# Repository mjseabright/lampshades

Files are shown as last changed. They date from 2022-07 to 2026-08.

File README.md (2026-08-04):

# Lampshades
A collection of 3D printable lampshades designed in OpenSCAD. More information on my [website](tartartech.xyz/lampshades) and STLs on [Printables](https://www.printables.com/social/308094-mjseabright/collections/207685).

## Where Are The STLs
They are [here](https://www.printables.com/social/308094-mjseabright/collections/207685). Some of them are quite big files, so they are hosted on Printables rather than GitHub. 

## Editing the Designs
All of the designs are done in [OpenSCAD](https://openscad.org/), so just [download](https://openscad.org/downloads.html) and install OpenSCAD and get to work. Each design's shape lives as a reusable module in `<design>.scad`, e.g. [turbine.scad](turbine/turbine.scad). To actually print one, open one of the sibling files that sets the dimensions and calls that module, e.g. [turbine_small.scad](turbine/turbine_small.scad) or [turbine_large.scad](turbine/turbine_large.scad) — that's where the main dimension parameters are, making them easily customisable. I suggest you change the layer height parameter to something like 2mm (rather than 0.2mm) while playing around with designs as it will be much quicker. Then change it back for the final render.

A couple of helper files at the repo root, [geometry_functions.scad](geometry_functions.scad) and [mounting_functions.scad](mounting_functions.scad), hold shapes shared across multiple designs (polygons, center holes, foot-mounting holes). You generally shouldn't need to touch these unless you want to change how the lampshade is mounted.

The [noise](noise/) design is different as it uses [Python](https://www.python.org/) to generate a SCAD file that then gets rendered via OpenSCAD. Changes can be made via the parmeters at the top of the [noisey_generator.py](noise/noisey_generator.py) file. Running it will generate a new [noisey.scad](noise/noisey.scad) file, which can then be rendered by OpenSCAD.

## Lamp Compatibility
I designed the lampshades to work with standard shade mounting systems. I've been using lamp bases that take an E14 bulb and have a ~28mm diameter male thread for the shade mounting. The [adaptor](adaptor/adaptor.scad) dimensions can be adjusted to fit larger light sockets.

Here is a picture of the socket on the lamp base I have been using:
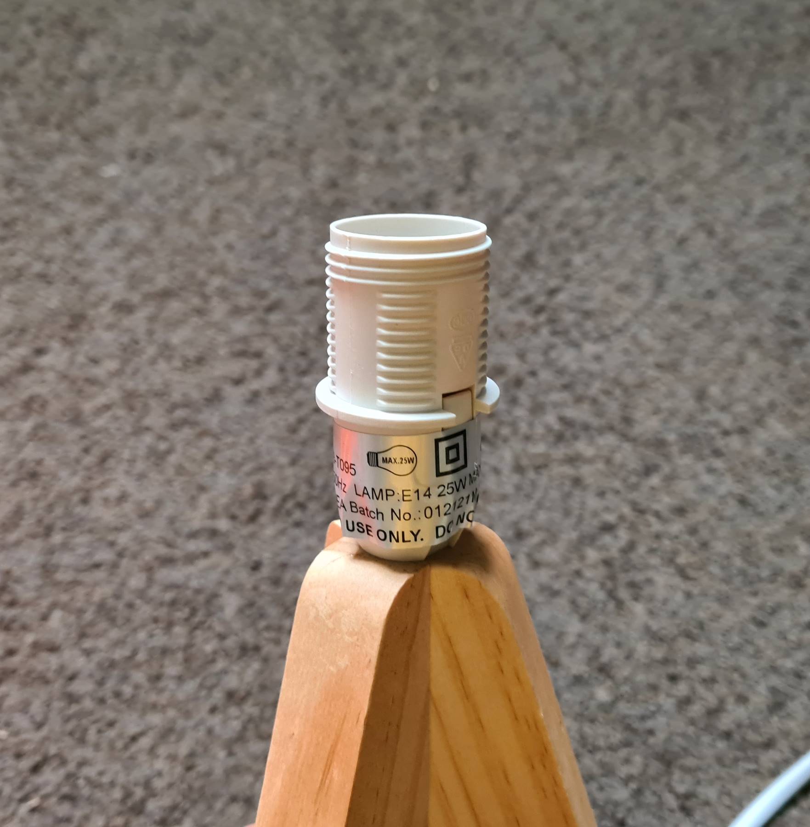
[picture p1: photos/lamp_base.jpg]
Lamp socket image


## Print Settings and Tips
All of these lampshades are designed to be printed in vase mode (single wall spiral printing). I used the following settings and found they worked well:
- Material: PETG (PLA works fine but may warp if you use an incandecent bulb or leave it in direct sunlight)
- Layer height: 0.2mm
- Line width: 0.6mm
- Solid bottom layers: 6
- Some of the designs look good using the ['fuzzy skin'](https://help.prusa3d.com/article/fuzzy-skin_246186) feature of PrusaSlicer or Cura

Print both the lampshade you like and the [adaptor](adaptor/adaptor.scad). I print the adaptor with normal settings (ie. not vase mode). I ususally use PETG and a 0.3mm layer height. It does require supports unfortunatly. Then glue the adaptor into the bottom of the lampshade with CA glue. Here are some pictures to show you what I mean:

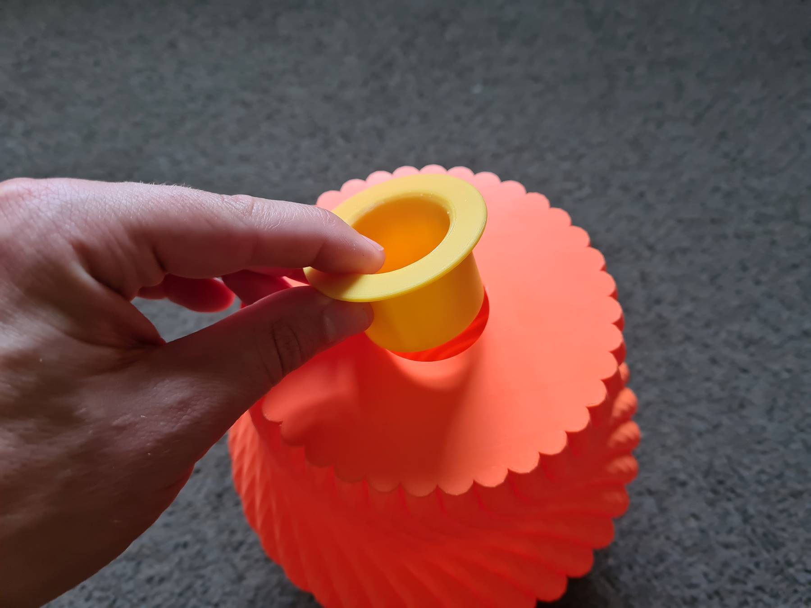
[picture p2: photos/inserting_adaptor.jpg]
Inserting the adaptor

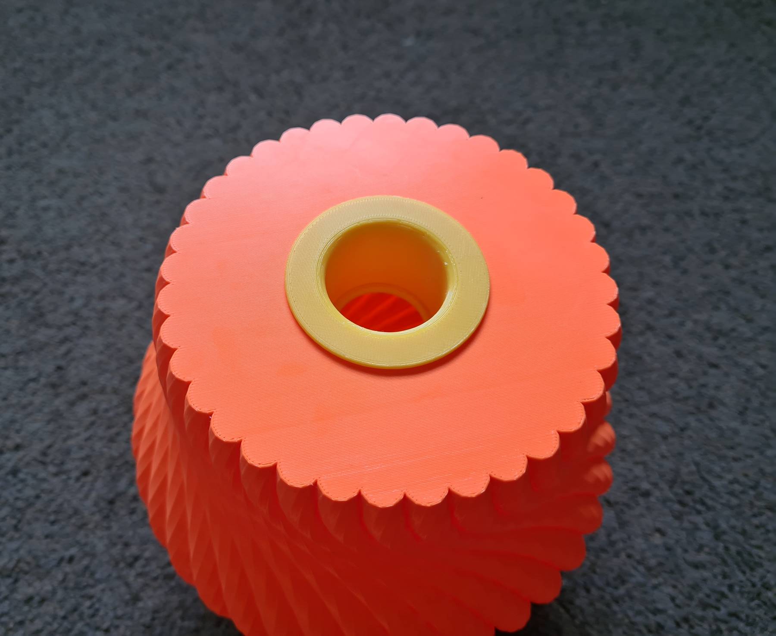
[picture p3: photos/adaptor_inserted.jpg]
Adaptor inserted


## Photos
See the [photos](photos/) folder for more photos of the designs.
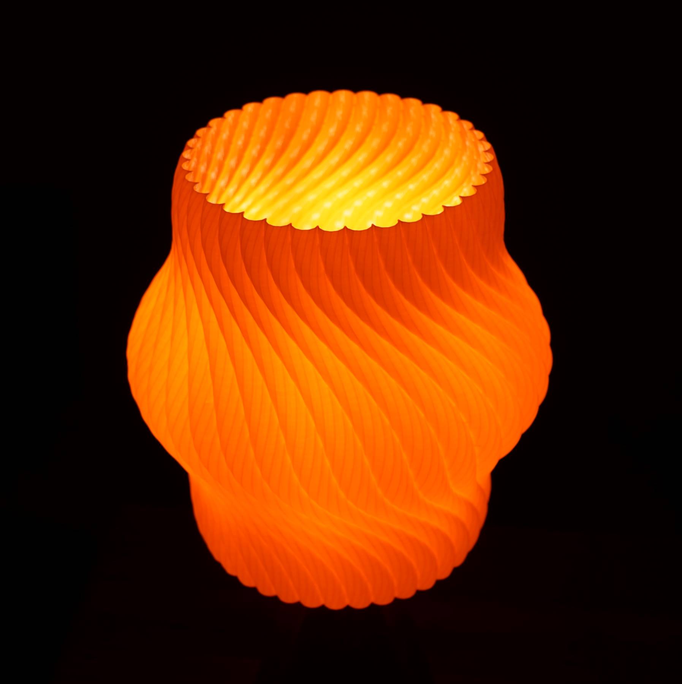
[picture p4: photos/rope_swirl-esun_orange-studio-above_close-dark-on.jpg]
A lamp

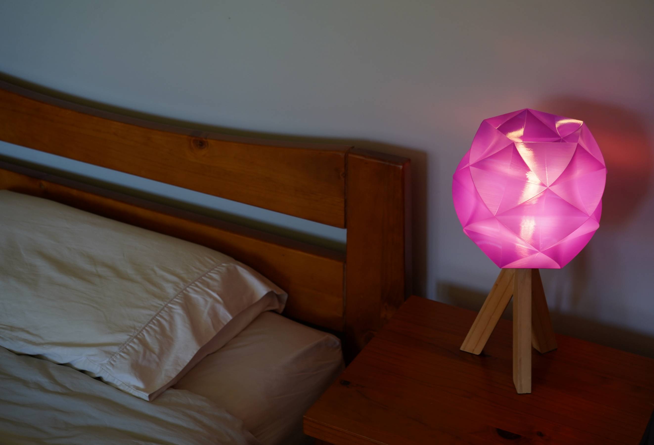
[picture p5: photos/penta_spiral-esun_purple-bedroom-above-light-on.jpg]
Another lamp

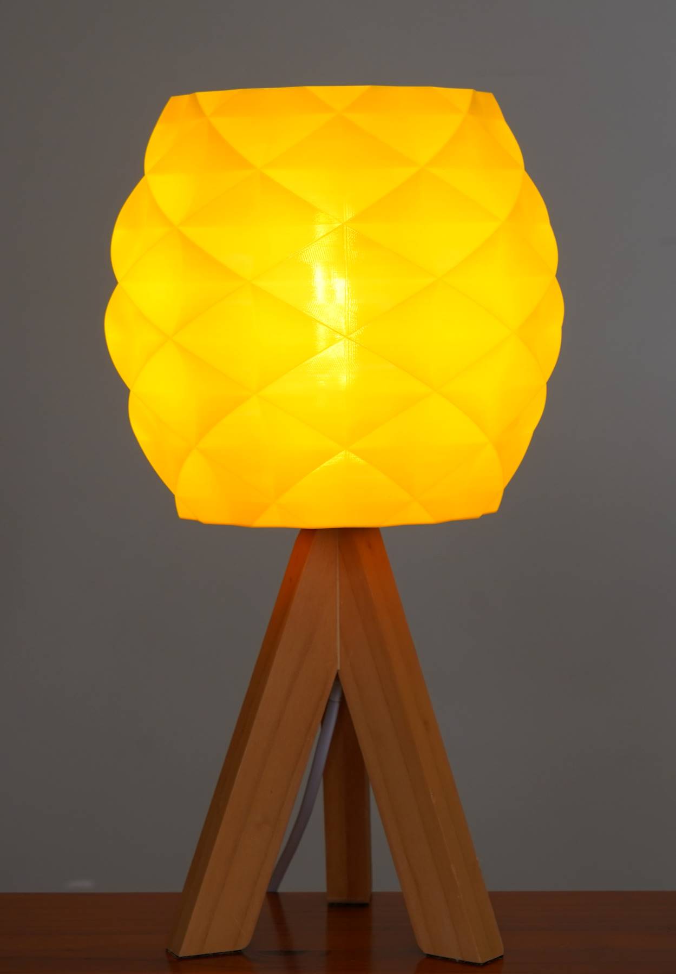
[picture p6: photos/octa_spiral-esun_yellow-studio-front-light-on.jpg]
Wow, another lamp


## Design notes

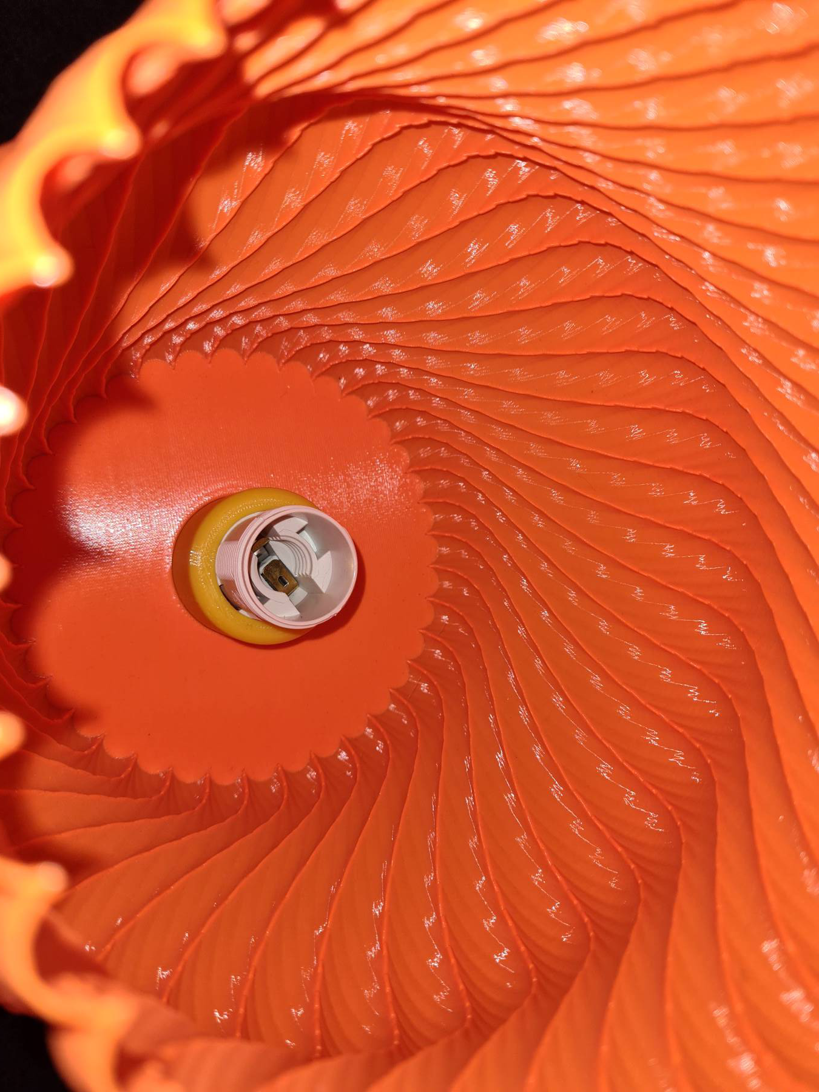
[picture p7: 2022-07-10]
photos/inside.jpg

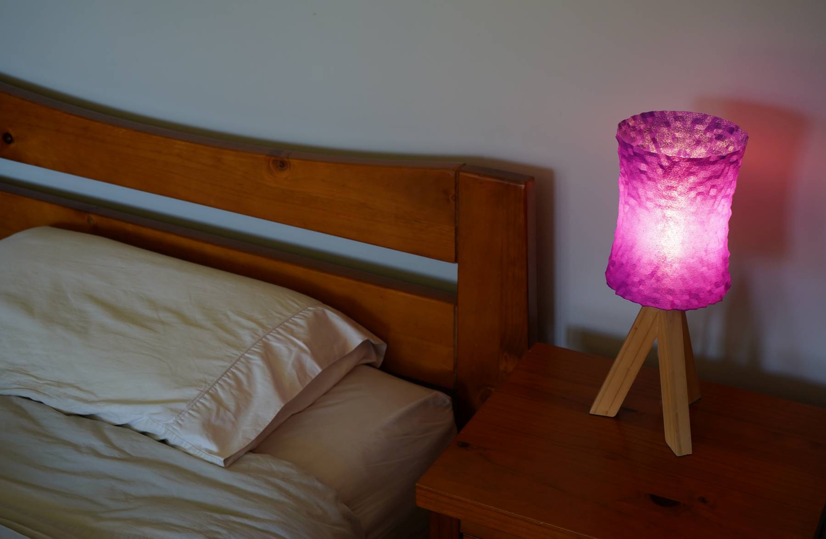
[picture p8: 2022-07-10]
photos/concave_noise_fuzz-esun_purple-bedroom-above-light-on.jpg

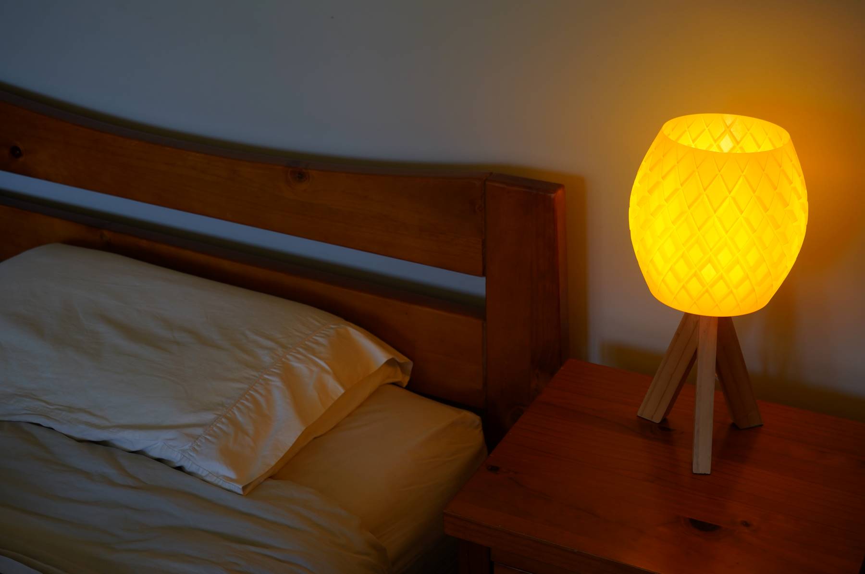
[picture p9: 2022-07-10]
photos/pineapple-esun_yellow-bedroom-above-light-on.jpg

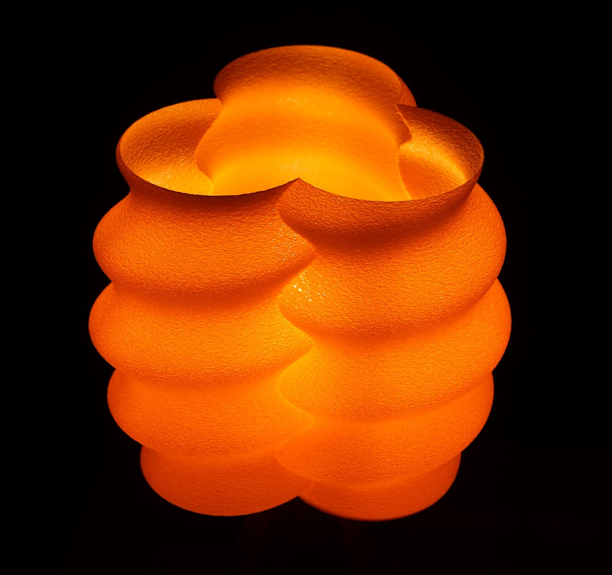
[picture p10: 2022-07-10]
photos/lava_swirl_fuzz-esun_orange-studio-above_close-dark-on.jpg

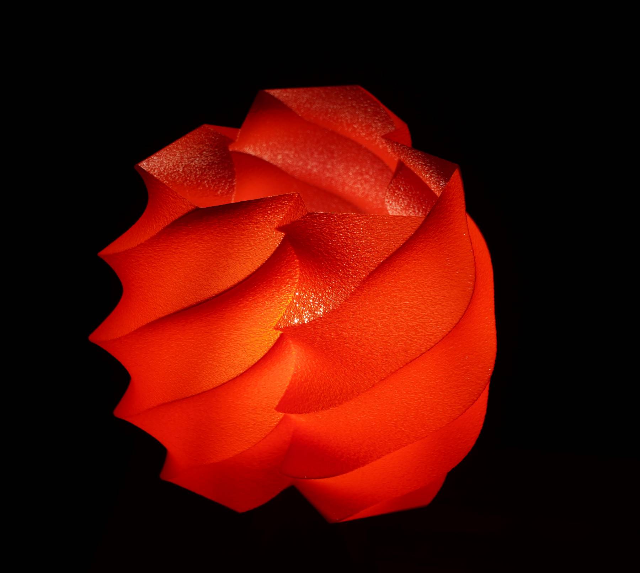
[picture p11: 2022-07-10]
photos/pentagon_turbine_fuzz-esun_red-studio-above_close-dark-on.jpg

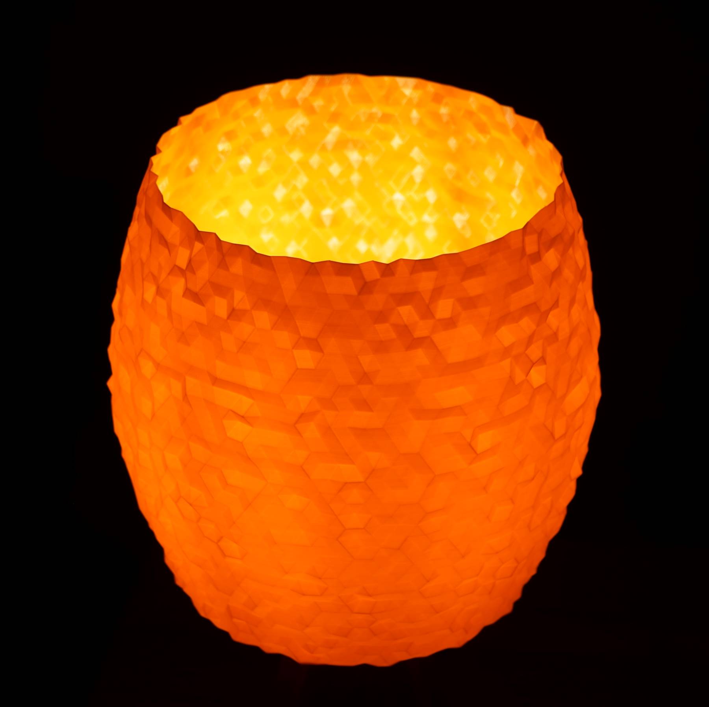
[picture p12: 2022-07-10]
photos/convex_noise-esun_orange-studio-above_close-dark-on.jpg

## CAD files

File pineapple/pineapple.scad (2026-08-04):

use <../geometry_functions.scad>;

module pineapple(height = 180, layer_height = 0.2, main_diameter = 130, num_angle_divs = 40) {
    for (h = [0:layer_height:height]) {
        layer_diameter = main_diameter + 40 * sin((h / height) * 180);
        triangle_ratio = ((h / 10) % 4 >= 2) ? (h / 10) % 2 : 2 - ((h / 10) % 2);

        translate([0,0,h]) linear_extrude (layer_height) intersection() {
            circle(d = layer_diameter + 0 + (12 * sin((h / height) * 180)), $fn=180);
            union() {
                for (theta = [0 : 2 * 360 / num_angle_divs : 360]) {
                    triangle_side_length = triangle_ratio * layer_diameter * cos(((num_angle_divs - 2) * 180) / (2 * num_angle_divs));
                    triangle_radius = regular_polygon_radius_from_side_length(order = 3, side_length = triangle_side_length);
                    triangle_position_offset = sqrt((layer_diameter / 2)^2 - (triangle_side_length / 2)^2);

                    rotate([0,0,theta]) translate([triangle_position_offset + triangle_radius * sin(30), 0, 0]) regular_polygon(order = 3, r = triangle_radius);
                }

                for (theta = [0 : 2 * 360 / num_angle_divs : 360]) {
                    triangle_side_length = (2 - triangle_ratio) * layer_diameter * cos(((num_angle_divs - 2) * 180) / (2 * num_angle_divs));
                    triangle_radius = regular_polygon_radius_from_side_length(order = 3, side_length = triangle_side_length);
                    triangle_position_offset = sqrt((layer_diameter / 2)^2 - (triangle_side_length / 2)^2);

                    rotate([0,0,theta + 360 / num_angle_divs]) translate([triangle_position_offset + triangle_radius * sin(30), 0, 0]) regular_polygon(order = 3, r = triangle_radius);
                }

                circle(d = layer_diameter + 0.5, $fn=180);
            }
        }
    }
}

// Standalone preview with default parameters
pineapple();

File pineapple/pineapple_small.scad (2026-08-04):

use <pineapple.scad>;
use <../mounting_functions.scad>;

height = 180;
layer_height = 0.2;
main_diameter = 130;
num_angle_divs = 40;
center_hole_diameter = 40;

difference() {
    pineapple(height = height, layer_height = layer_height, main_diameter = main_diameter, num_angle_divs = num_angle_divs);
    center_hole(height = height, diameter = center_hole_diameter);
}

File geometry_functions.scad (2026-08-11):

module regular_polygon(order = 5, r=1){
     angles=[ for (i = [0:order-1]) i*(360/order) ];
     coords=[ for (th=angles) [r*cos(th), r*sin(th)] ];
     polygon(coords);
 }

function regular_polygon_side_length(order = 3, r = 1) = 2 * r * sin(360 / (2 * order));
function regular_polygon_radius_from_side_length(order = 3, side_length = 10) = side_length / (2 * sin(360 / (2 * order)));

// Solid cylinder with its outer top and/or bottom edge chamfered (45 degrees
// by default, since the radial and vertical cut both equal `chamfer`). Set
// chamfer_top/chamfer_bottom to false for an end that isn't a real exposed
// face (e.g. it butts against another part) -- chamfering a hidden seam
// creates a visible necked-in groove where the two parts meet.
module chamfered_cylinder(h, d, chamfer, fn = 64, chamfer_top = true, chamfer_bottom = true) {
    r = d / 2;
    bottom_pts = chamfer_bottom ? [[0, 0], [r - chamfer, 0], [r, chamfer]] : [[0, 0], [r, 0]];
    top_pts = chamfer_top ? [[r, h - chamfer], [r - chamfer, h], [0, h]] : [[r, h], [0, h]];
    rotate_extrude($fn = fn) polygon(points = concat(bottom_pts, top_pts));
}

// Cutter for a hole with a countersink chamfer at the z=0 and/or z=h faces.
// Subtract this instead of a plain cylinder to chamfer a hole's edges.
// Self-extends slightly past both faces, so no manual translate/epsilon is
// needed at the call site. Set chamfer_top/chamfer_bottom to false for a
// blind end that isn't a real exposed face -- otherwise the countersink
// flares open inside the solid instead of breaking a real edge.
module chamfered_hole(h, d, chamfer, fn = 32, chamfer_top = true, chamfer_bottom = true) {
    eps = 0.5;
    z0 = chamfer_bottom ? -eps : 0;
    z1 = chamfer_top ? h + eps : h;
    union() {
        translate([0, 0, z0]) cylinder(h = z1 - z0, d = d, $fn = fn);
        if (chamfer_bottom) {
            cylinder(h = chamfer, d1 = d + 2 * chamfer, d2 = d, $fn = fn);
        }
        if (chamfer_top) {
            translate([0, 0, h - chamfer]) cylinder(h = chamfer, d1 = d, d2 = d + 2 * chamfer, $fn = fn);
        }
    }
}

// Linear-extrudes a CONVEX 2D child shape into a solid with both the top and
// bottom outer edges chamfered, by hull-lofting a shrunk copy of the profile
// up to full size over the chamfer height at each end. Only valid for convex
// profiles -- hull() will fill in any concavity (e.g. a hole), so cut those
// afterwards with a separate difference(), not inside the extruded child.
module chamfered_extrude(h, chamfer) {
    union() {
        hull() {
            linear_extrude(0.01) offset(delta = -chamfer) children();
            translate([0, 0, chamfer]) linear_extrude(0.01) children();
        }
        translate([0, 0, chamfer]) linear_extrude(h - 2 * chamfer) children();
        hull() {
            translate([0, 0, h - chamfer]) linear_extrude(0.01) children();
            translate([0, 0, h - 0.01]) linear_extrude(0.01) offset(delta = -chamfer) children();
        }
    }
}

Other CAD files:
mounting_functions.scad
adaptor/adaptor.scad
bases/low_pro_with_adaptor.scad
double_rotated_octagon/rotated_octogon.scad
double_rotated_octagon/rotated_octogon_small.scad
double_rotated_pentagon/double_rotated_pentagon.scad
double_rotated_pentagon/double_rotated_pentagon_small.scad
feet/low_profile_foot.scad
feet/low_profile_foot_insert.scad
feet/low_profile_foot_plastic_thread.scad
fish_tail/fish_tail.scad
fish_tail/fish_tail_small.scad
golfball/golfball.scad
golfball/golfball_small.scad
noise/noisey.scad
rope_swirl/rope_swirl.scad
rope_swirl/rope_swirl_large.scad
rope_swirl/rope_swirl_large_base.scad
rope_swirl/rope_swirl_small.scad
rotated_star/rotated_star.scad
rotated_star/rotated_star_small.scad
screw_compressor/screw_compressor.scad
screw_compressor/screw_compressor_small.scad
triple_spring/triple_spring.scad
triple_spring/triple_spring_small.scad
turbine/turbine.scad
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

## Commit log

2022-07-10 Added all the things
    [adaptor.scad, double_rotated_pentagon.scad, golfball.scad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]
2022-07-13 Added fish tail
    [fish_tail.scad]
2026-08-01 Add turbine_large.scad, a scaled-up variant of turbine.scad for larger printers
    Scaled to fit a 256mm build volume (240mm height, ~240mm XY), with twist
    rates expressed as full rotations over height, named/commented variables
    throughout, and separate center/foot mounting holes.
    [turbine.scad, turbine_large.scad]
2026-08-04 Refactor designs into reusable geometry modules with separate config files
    Each design's core shape now lives in a parameterized module in <design>.scad,
    so the same geometry can be reused across different size/mounting configs
    instead of being duplicated per variant. <design>_small.scad (and
    turbine_large.scad) hold the parameters for a specific variant and add
    mounting features on top.
    Shared helpers pulled out to their own files: regular_polygon and friends
    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
    [double_rotated_pentagon.scad, double_rotated_pentagon_small.scad, fish_tail.scad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]
2026-08-04 Update README to reflect module/config-file refactor
    Editing the Designs now points at the <design>_small/_large config files
    for dimensions rather than the module file itself, and mentions the shared
    geometry_functions.scad/mounting_functions.scad helpers.
2026-08-04 Add bullet-shaped foot design with insert and plastic-thread variants
    Outer profile is a bezier nose revolved with rotate_extrude, tangent to
    the cylindrical body so there's no sharp shoulder, tapering to a rounded
    point. The two variants share the same foot.scad module and differ only
    in center hole diameter (threaded insert vs. self-tapping screw).
    [foot.scad, low_profile_foot_insert.scad, low_profile_foot_plastic_thread.scad]
2026-08-04 Rename feet/foot.scad to low_profile_foot.scad
    Clarifies that this module is specifically for the low-profile foot
    design, not a generic foot shape. Update the variant files' use
    statements accordingly.
    Also pick up a small README wording tweak.
    [low_profile_foot.scad, low_profile_foot_insert.scad, low_profile_foot_plastic_thread.scad]
2026-08-05 Add reusable base module and turbine_large base file
    low_pro_with_adaptor is a placeholder base module (spokes, foot holes,
    adaptor mount boss) in bases/, plus turbine_large_base.scad which wires
    it up with turbine_large.scad's shared parameters so the shade and base
    render as separate STLs.
    [low_pro_with_adaptor.scad, turbine_large.scad, turbine_large_base.scad]
2026-08-11 Taper spokes and flesh out low_pro_with_adaptor base geometry
    Spokes now taper from a wider spoke_width_center at the hub down to
    spoke_width at the foot-hole tip instead of being constant-width
    rectangles. Also fills in the previously placeholder spoke/rim geometry
    and tunes mount/spoke dimensions, wired through in turbine_large_base.
    [low_pro_with_adaptor.scad, turbine_large_base.scad]
2026-08-11 Add chamfered top/bottom edges to low_pro_with_adaptor base
    Adds chamfered_cylinder, chamfered_hole, and chamfered_extrude helpers
    to geometry_functions.scad and uses them throughout the base's boss,
    disc, spokes, and holes so every real exposed XY-plane face gets a
    0.5mm edge break, without chamfering hidden seams or blind ends.
    The mount boss is split into a main body and a separate top lip so the
    mount_id bore can stop cleanly (blind, no chamfer) under the lip, and
    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
    [geometry_functions.scad, low_pro_with_adaptor.scad, turbine_large_base.scad]
2026-08-16 Add rope_swirl_large with base, and parametrize spiral shape
    Conform rope_swirl_large.scad to repo conventions: call the shared
    rope_swirl() module (like rope_swirl_small.scad does) instead of
    duplicating its layer-loop geometry, and cut mounting holes via
    mounting_functions.scad instead of hand-rolled per-layer holes.
    To preserve rope_swirl_large's distinct octagon/twist-speed look
    through the shared module, extend rope_swirl() with circle_sides,
    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
    [rope_swirl.scad, rope_swirl_large.scad, rope_swirl_large_base.scad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]
2026-08-16 Tune mount/blade parameters and ignore STL exports
    Bump the adaptor mount boss height to 65mm on rope_swirl_large_base
    and turbine_large_base, tweak turbine_large's blade shape/rotation,
    and add a .gitignore so exported .stl files aren't tracked.
    [rope_swirl_large_base.scad, turbine_large.scad, turbine_large_base.scad]
2026-08-29 Lengthen low profile foot and flatten nose profile
    [low_profile_foot.scad, low_profile_foot_insert.scad, low_profile_foot_plastic_thread.scad]
2026-08-29 Add turbine_random variant and slow-fast-slow twist_variation option
    turbine_random.scad/turbine_random_large.scad add smoothly-noised twist
    rate, swell, and per-blade phase/amplitude so blades don't spin in a
    perfectly clean, uniform spiral. turbine.scad/turbine_large.scad gain a
    twist_variation parameter that eases the twist rate to be slower at the
    top/bottom and faster through the middle while keeping the total number
    of rotations fixed at blade_rotations.
    [turbine.scad, turbine_random.scad, turbine_random_large.scad]
2026-08-31 Reduce turbine_large layer_height to 0.2mm for finer resolution
    [turbine_large.scad]
